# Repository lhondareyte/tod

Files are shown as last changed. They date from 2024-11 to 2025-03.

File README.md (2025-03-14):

## Top Octave Frequency generator

An  attempt to build a top octave divider. This can also be used to make any static prescaler.

## Restrictions

### DC Characteristics

Original MOSTEK chips require a supply voltage of ~15v (Max 16v). Input clock voltage must be between 0v and Vss -1v min. To avoid this, a TTL compatible master clock is include in schematic (Typical clock frequency is 2.00024 MHz).

### Duty cycle

MOSTEK chips differs in their number of dividers and duty cycle :

* MK50240 : 50% - 13 dividers (239 to 478)
* MK50241 : 30% - 13 dividers (239 to 478)
* MK50242 : 50% - 12 dividers (239 to 451)

This emulation only generate a (almost) 50% duty cycle. Thereby,  MK50241 model is not supported since the timbre will be affected. 

## Power consumption

Original MOSTEK chips sink 24mA@15V : 0.36w Typ. (Max 37mA@15V = 0.56W). You need 13 attiny4/13 to emulate a MK50240 (12 for a MK50242). Total power consumption for 13 ATtiny13 is about 30mA@5V (Not include clock circuitry).

## TODO

* Support 30% duty cycle

## Other use

The script `genedivider.pl` can be use to generate assembly code for any static prescaler. For example, to build a `by 42` prescaler:

    ./genedivide.pl 42 > divide.S

If an overflow/underflow occurs you can try to adjust `$loop` variable:

    ./genedivide.pl 10000 200 > divide.S

Warning, the script do not check the generated code size.

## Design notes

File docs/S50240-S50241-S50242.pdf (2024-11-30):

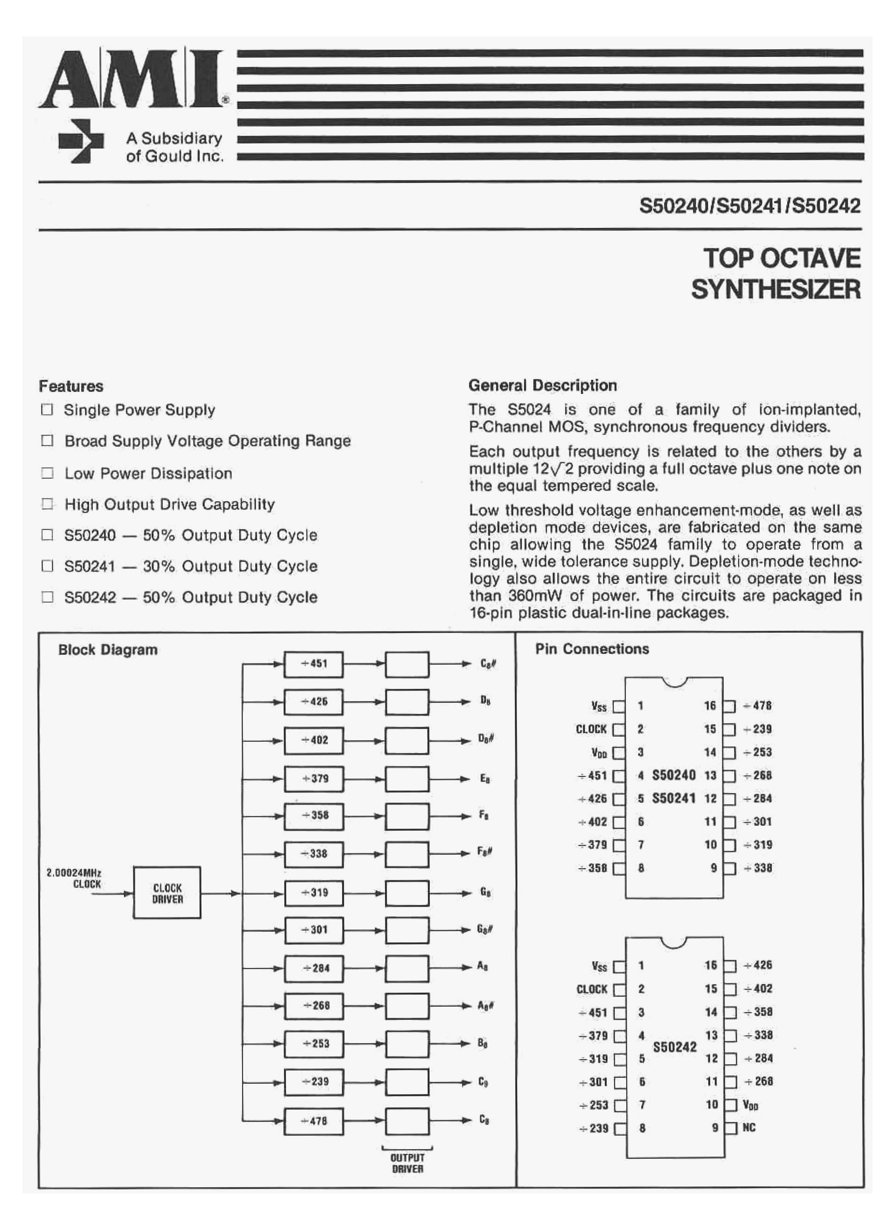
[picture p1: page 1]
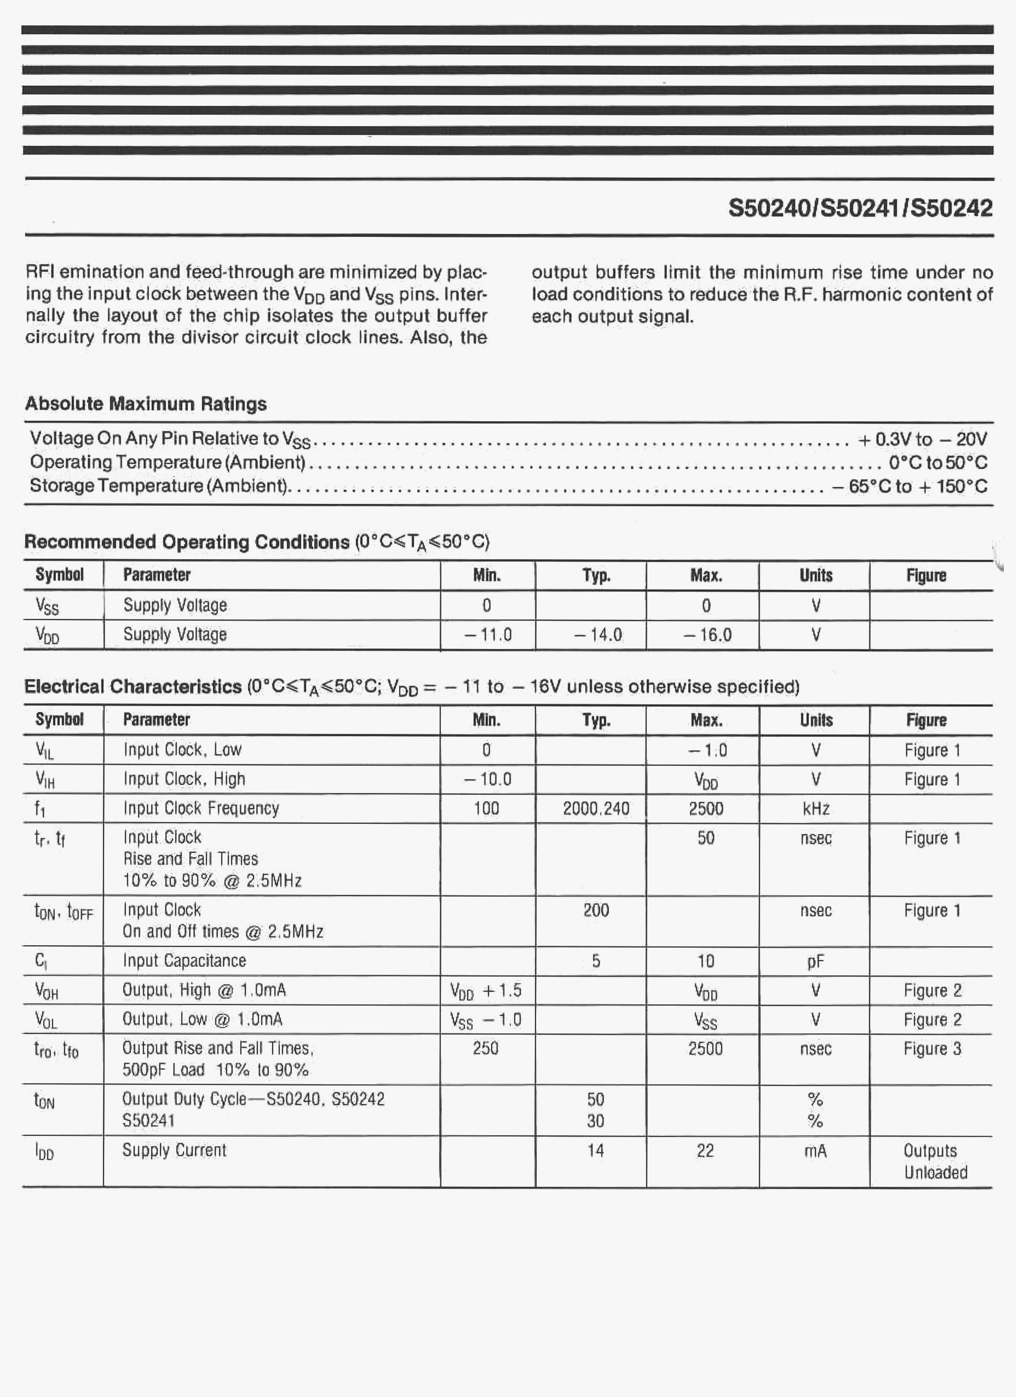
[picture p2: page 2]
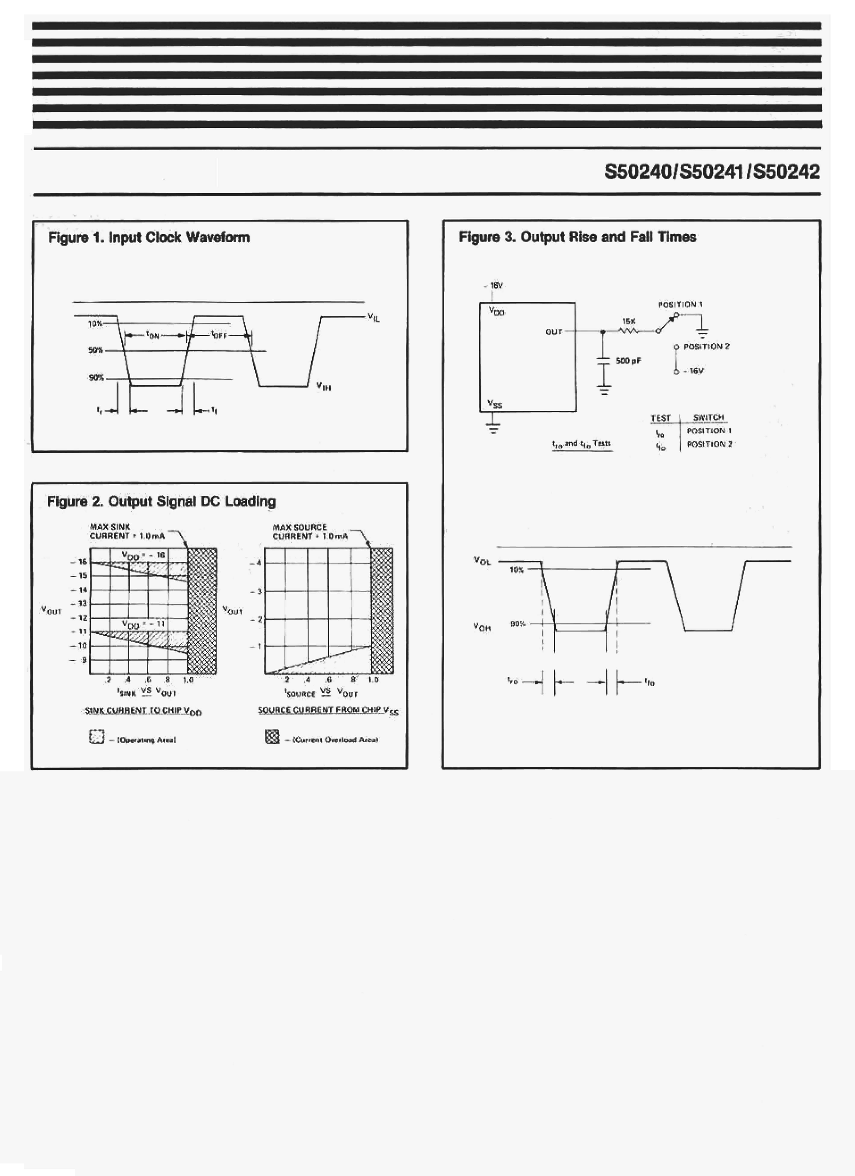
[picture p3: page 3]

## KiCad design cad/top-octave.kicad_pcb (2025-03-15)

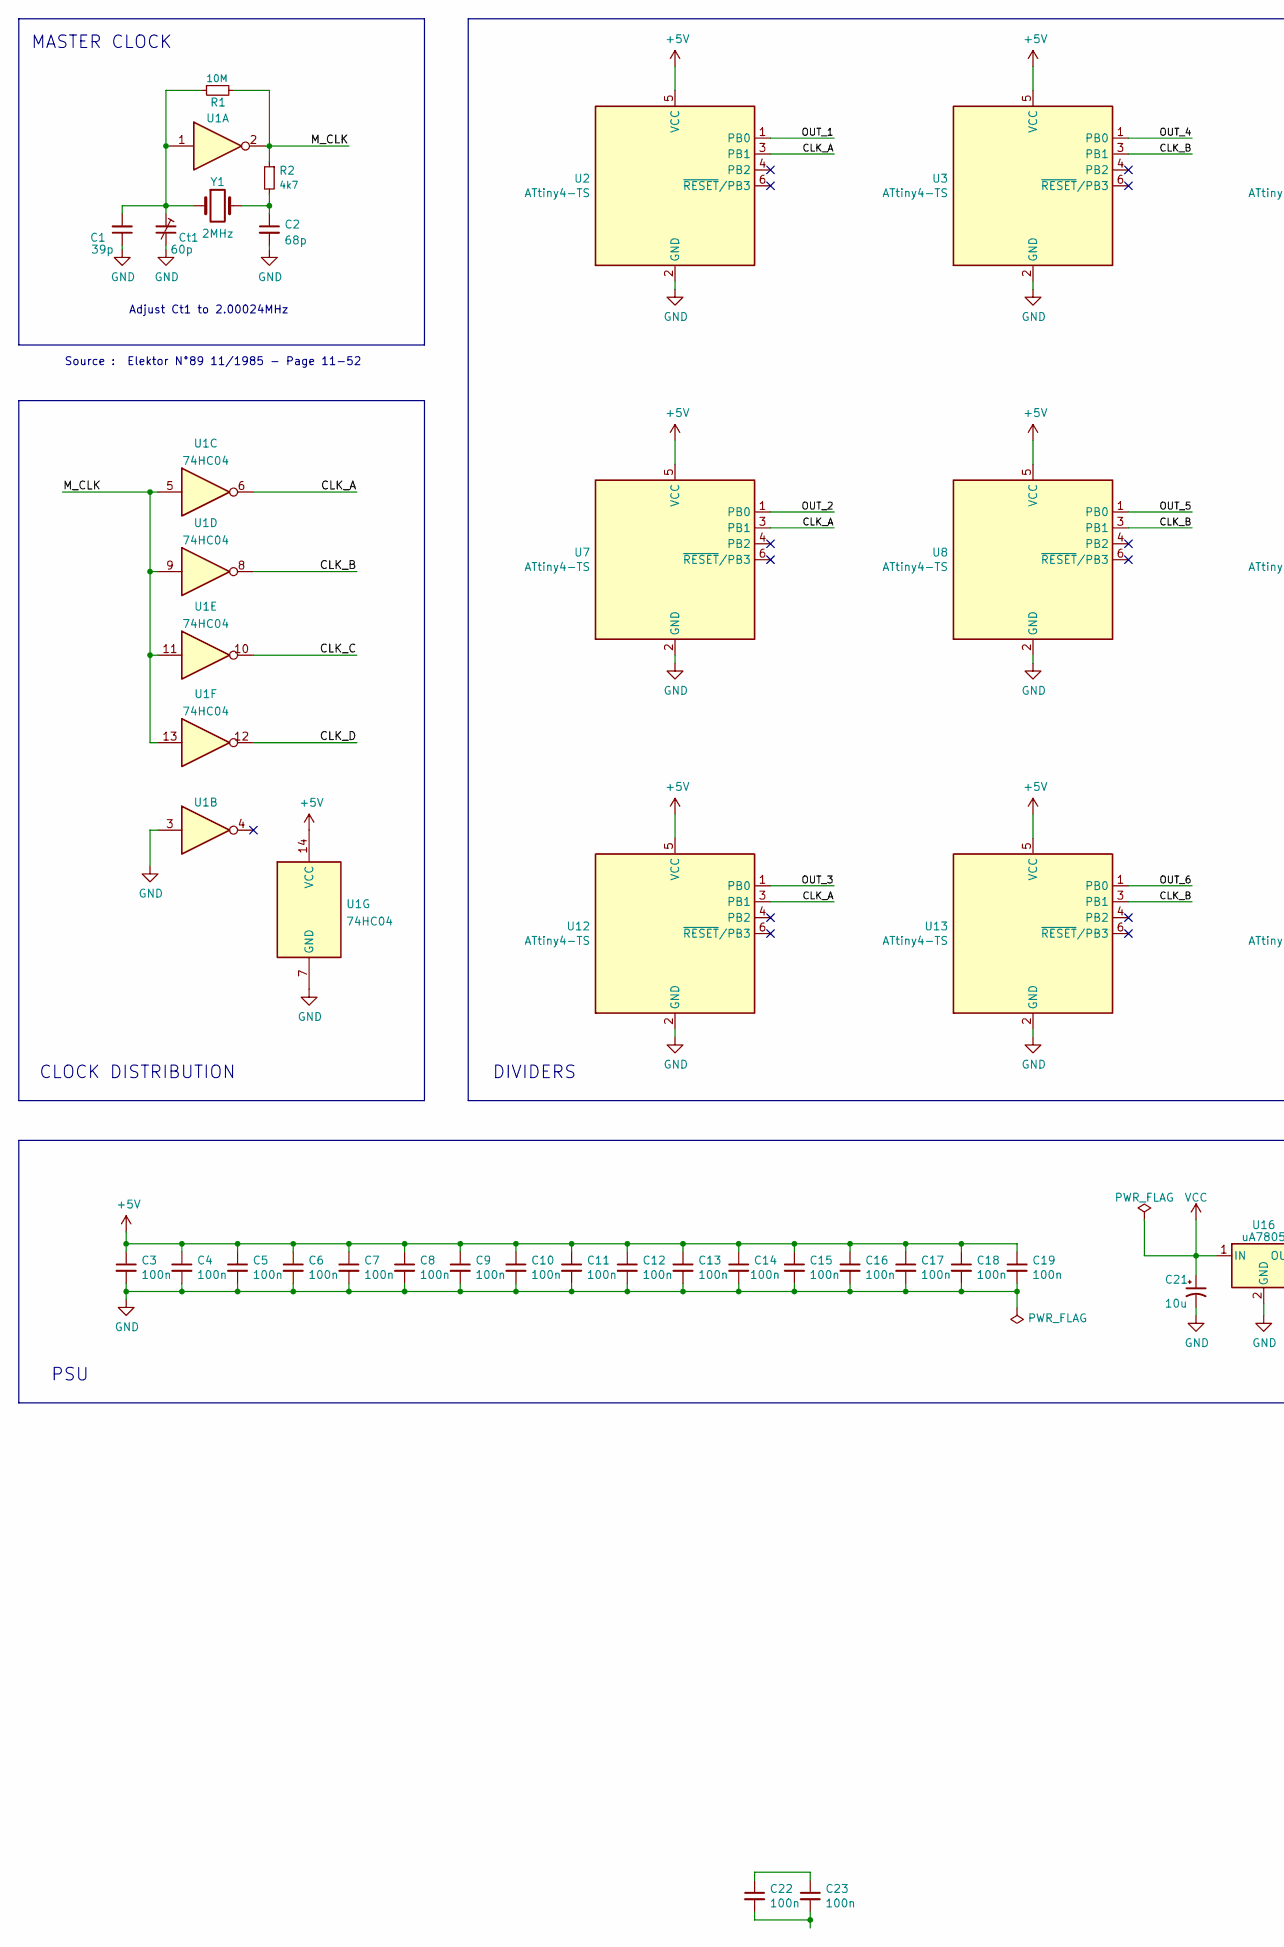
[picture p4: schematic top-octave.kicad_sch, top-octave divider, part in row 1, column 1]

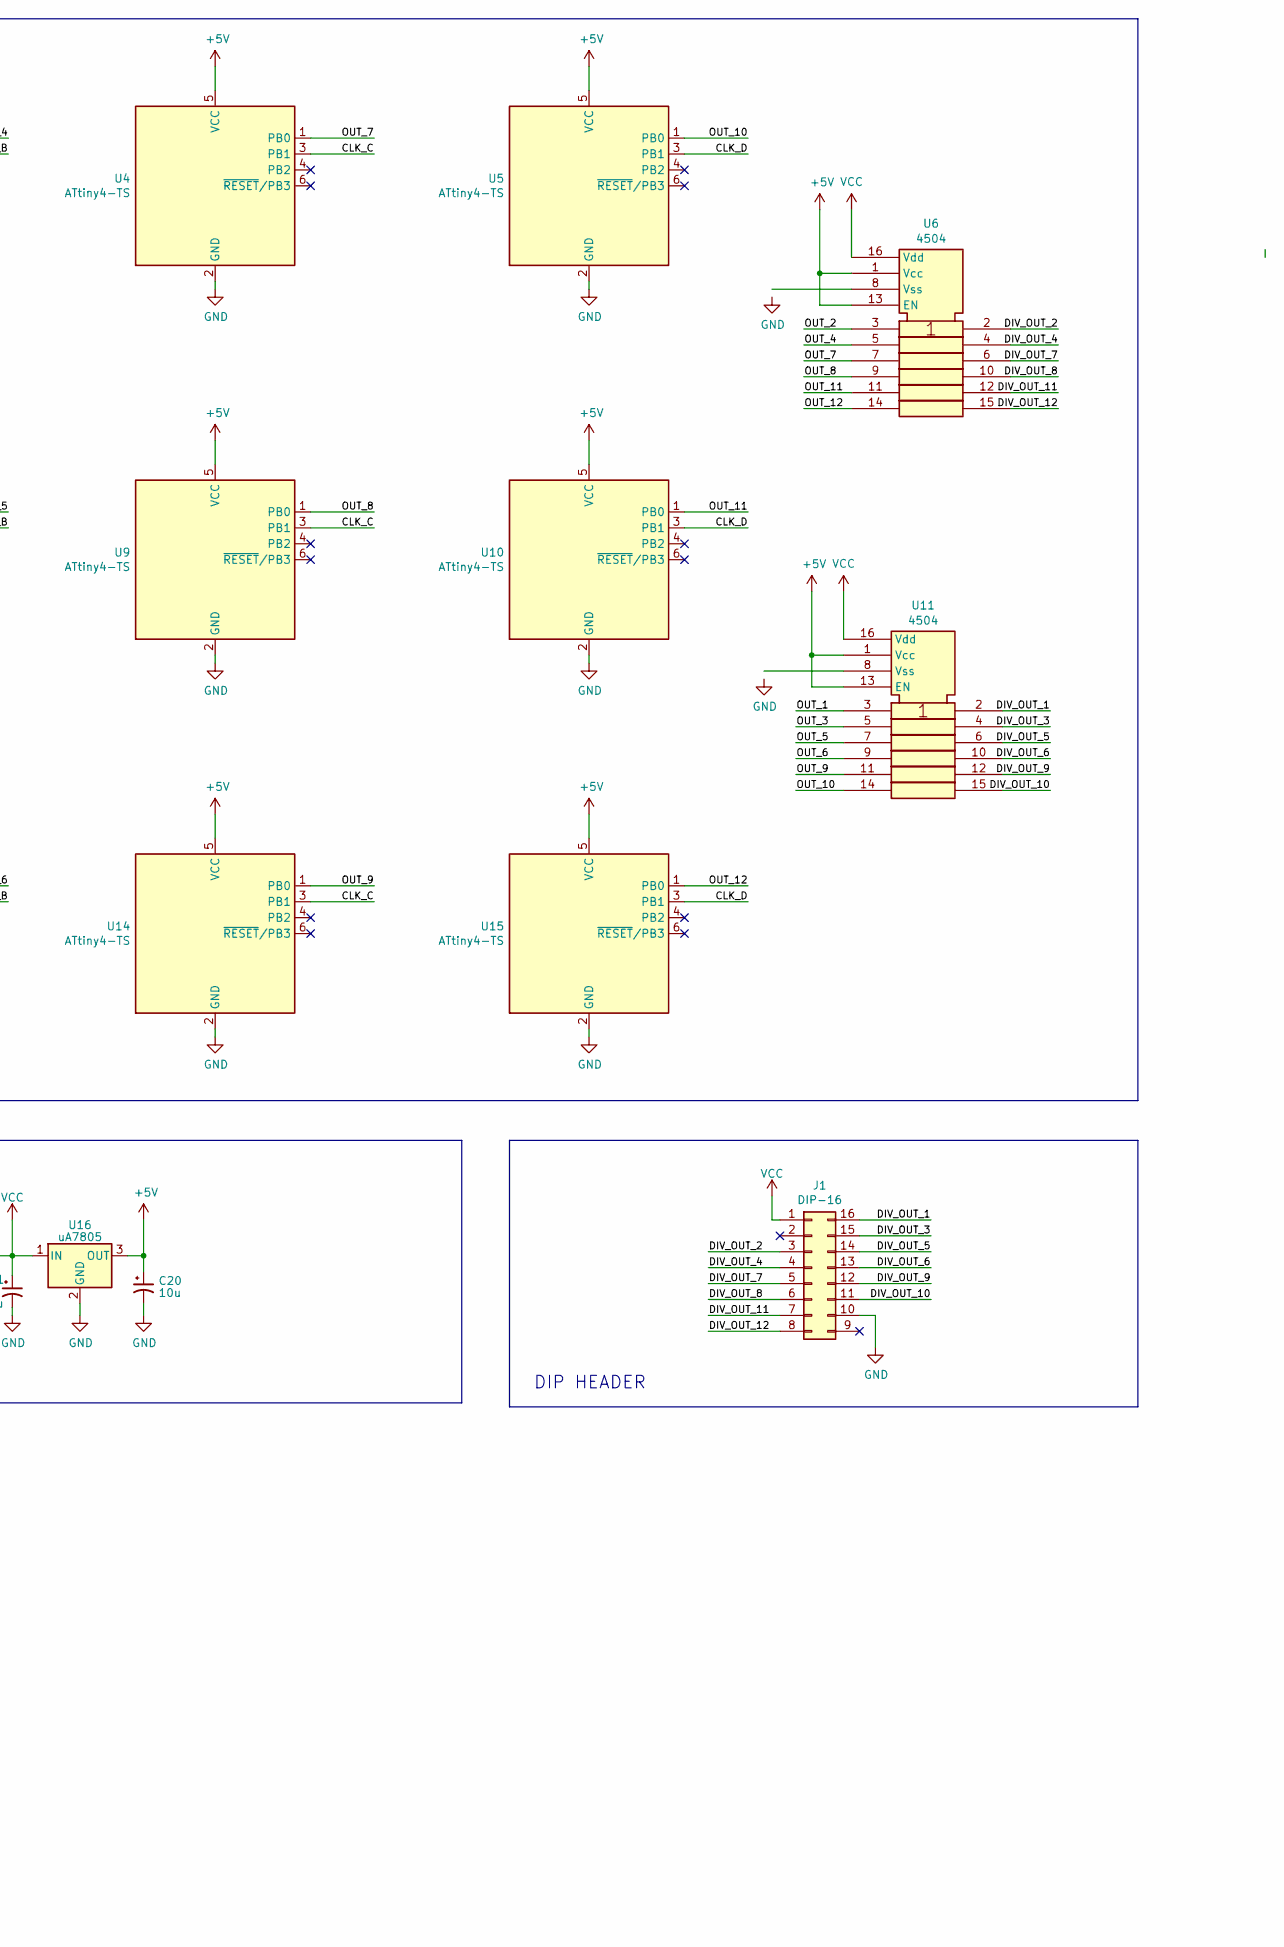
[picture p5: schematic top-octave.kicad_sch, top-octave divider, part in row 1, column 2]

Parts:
C1: 39p; C_1206_3216Metric
C2: 68p; C_1206_3216Metric
C3, C4, C5, C6, C7, C8, C9, C10, C11, C12, C13, C14, C15, C16, C17, C18, C19, C22, C23: 100n; R_0805_2012Metric_Pad1.20x1.40mm_HandSolder
C20, C21: 10u
Ct1: 60p
J1: DIP-16; DIP-16_W7.62mm_Socket
R1: 10M; R_0805_2012Metric_Pad1.20x1.40mm_HandSolder
R2: 4k7; R_0805_2012Metric_Pad1.20x1.40mm_HandSolder
U1: 74HC04; SOIC-14_3.9x8.7mm_P1.27mm
U2, U3, U4, U5, U7, U8, U9, U10, U12, U13, U14, U15: ATtiny4-TS; SOT-23-6
U6, U11: 4504; SO-16_3.9x9.9mm_P1.27mm
U16: uA7805; SOT-223
Y1: 2MHz; SOT-89-5

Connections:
+5V: C3.1, C4.1, C5.1, C6.1, C7.1, C8.1, C9.1, C10.1, C11.1, C12.1, C13.1, C14.1, C15.1, C16.1, C17.1, C18.1, C19.1, C20.1, U1.14 (VCC), U2.5 (VCC), U3.5 (VCC), U4.5 (VCC), U5.5 (VCC), U6.1 (Vcc), U6.13 (EN), U7.5 (VCC), U8.5 (VCC), U9.5 (VCC), U10.5 (VCC), U11.1 (Vcc), U11.13 (EN), U12.5 (VCC), U13.5 (VCC), U14.5 (VCC), U15.5 (VCC), U16.3 (OUT)
/CLK_A: U1.6, U2.3 (PB1), U7.3 (PB1), U12.3 (PB1)
/CLK_B: U1.8, U3.3 (PB1), U8.3 (PB1), U13.3 (PB1)
/CLK_C: U1.10, U4.3 (PB1), U9.3 (PB1), U14.3 (PB1)
/CLK_D: U1.12, U5.3 (PB1), U10.3 (PB1), U15.3 (PB1)
/DIV_OUT_1: J1.16, U11.2
/DIV_OUT_2: J1.3, U6.2
/DIV_OUT_3: J1.15, U11.4
/DIV_OUT_4: J1.4, U6.4
/DIV_OUT_5: J1.14, U11.6
/DIV_OUT_6: J1.13, U11.10
/DIV_OUT_7: J1.5, U6.6
/DIV_OUT_8: J1.6, U6.10
/DIV_OUT_9: J1.12, U11.12
/DIV_OUT_10: J1.11, U11.15
/DIV_OUT_11: J1.7, U6.12
/DIV_OUT_12: J1.8, U6.15
/M_CLK: R1.2, R2.1, U1.2, U1.5, U1.9, U1.11, U1.13
/OUT_1: U2.1 (PB0), U11.3
/OUT_2: U6.3, U7.1 (PB0)
/OUT_3: U11.5, U12.1 (PB0)
/OUT_4: U3.1 (PB0), U6.5
/OUT_5: U8.1 (PB0), U11.7
/OUT_6: U11.9, U13.1 (PB0)
/OUT_7: U4.1 (PB0), U6.7
/OUT_8: U6.9, U9.1 (PB0)
/OUT_9: U11.11, U14.1 (PB0)
/OUT_10: U5.1 (PB0), U11.14
/OUT_11: U6.11, U10.1 (PB0)
/OUT_12: U6.14, U15.1 (PB0)
GND: C1.1, C2.2, C3.2, C4.2, C5.2, C6.2, C7.2, C8.2, C9.2, C10.2, C11.2, C12.2, C13.2, C14.2, C15.2, C16.2, C17.2, C18.2, C19.2, C20.2, C21.2, Ct1.2, J1.10, U1.3, U1.7 (GND), U2.2 (GND), U3.2 (GND), U4.2 (GND), U5.2 (GND), U7.2 (GND), U8.2 (GND), U9.2 (GND), U10.2 (GND), U12.2 (GND), U13.2 (GND), U14.2 (GND), U15.2 (GND), U16.2 (GND)
unnamed: C1.2, Ct1.1, R1.1, U1.1, Y1.1
unnamed: C2.1, R2.2, Y1.2
unnamed: C22.1, C23.1
unnamed: C22.2, C23.2
VCC: C21.1, J1.1, U6.16 (Vdd), U11.16 (Vdd), U16.1 (IN)

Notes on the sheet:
MASTER CLOCK
DIVIDERS
DIP HEADER
Adjust Ct1 to 2.00024MHz
PSU
Source : Elektor N°89 11/1985 - Page 11-52
CLOCK DISTRIBUTION

Board: 2 copper layers, 41 parts (0 on the bottom side), 36 nets, no tracks yet.

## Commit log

2022-08-19 Import KiCad files
    [top-octave.kicad_pcb, top-octave.kicad_sch]
2022-11-19 Update schematic
    [top-octave.kicad_sch]
2022-11-25 Fix level shifter
    [top-octave.kicad_sch]
2024-04-27 Fix wrong header for MK50242
    [top-octave.kicad_pcb, top-octave.kicad_sch]
2024-11-30 gstabs switch is no longer supported
2025-03-15 Replace all mosfet by 2 cd4504
    [top-octave.kicad_pcb, top-octave.kicad_sch]
